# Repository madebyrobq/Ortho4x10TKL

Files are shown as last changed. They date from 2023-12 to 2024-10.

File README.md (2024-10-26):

# Ortho 4x10 TKL v0.1

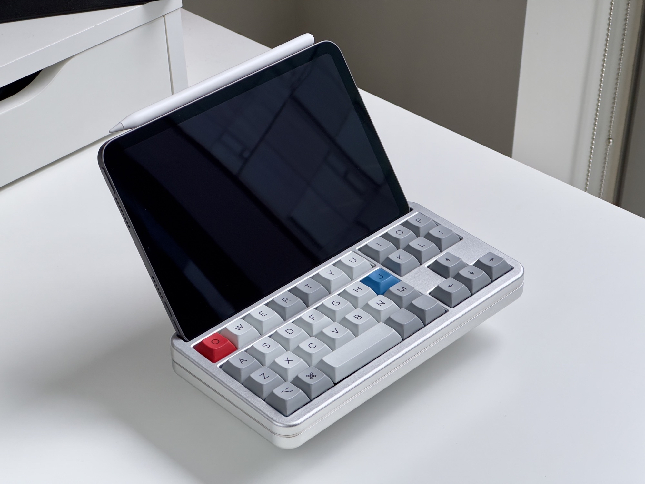
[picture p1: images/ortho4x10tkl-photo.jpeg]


### Summary

An open-source custom mechanical keyboard featuring
* 4x10 ortholinear 'tenkeyless' style layout
* Raspberry Pi RP2040 integrated microcontroller
* USB-C
* Hotswap sockets
* Fully factory-assembled PCBA
* QMK Vial firmware

### Goals

The goals of this project were:
1. Learn how to make a working PCBA mechanical keyboard
2. Keep hardware features to the minimum (no LEDs, OLED, encoders, etc.)
3. Fun and delighful > practical
4. Companion for iPad Mini (6th gen)

### Layout

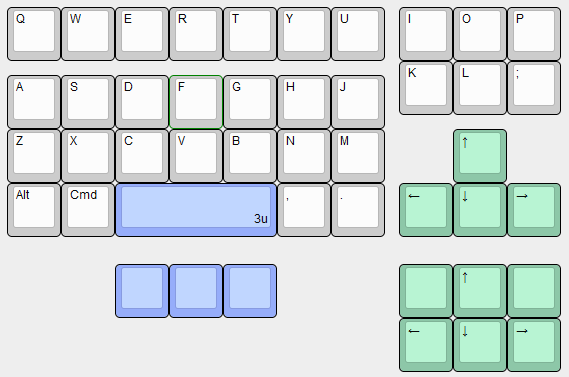
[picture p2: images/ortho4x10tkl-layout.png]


Spacebar cluster supports 3x1U and 1x3U layouts. Stabilizers are not currently supported but can be substituted with loose switches if desired.

Arrow cluster supports 4 or 6 keys, although the top cases in this repo will cover up 2 of them. Still, the switches are there if you prefer to have them.

### Keymap

This is my keymap, note that with VIAL firmware some setup will be manual in the VIAL application or loaded from a saved layout

```
Default Layer:
┌───────┬───────┬───────┬───────┬───────┬───────┬───────┐┌───────┬───────┬───────┐
│   Q (TAB) W   │   E   │   R   │   T   │   Y   │   U   ││   I   │   O (DEL) P   │
└───────┴───────┴───────┴───────┴───────┴───────┴───────┘├───────┼───────┼───────┤
┌───────┬───────┬───────┬───────┬───────┬───────┬───────┐│   K   │   L (ENT) ;   │
│   A (ESC) S   │   D   │   F   │   G   │   H   │   J   │└───────┴───────┴───────┘
├───────┼───────┼───────┼───────┼───────┼───────┼───────┤┌       ┌───────┐       ┐
│  Z(⇧) │   X   │   C   │   V   │   B   │   N   │  M(⇧) │  PG DN │   Up  │ PG UP
├───────┼───────┼───────┼───────┼───────┼───────┼───────┤┌───────┼───────┼───────┐
│   ⌥   │   ⌘   │         Space         │   ,   │   .   ││  Left │  Down │ Right │
└───────┴───────┴───────┴───────┴───────┴───────┴───────┘└───────┴───────┴───────┘

Raise Layer:
┌───────┬───────┬───────┬───────┬───────┬───────┬───────┐┌───────┬───────┬───────┐
│   1  (`)  2   │   3   │   4   │   -   │   +   │       ││   [   │   ]   |   '   │
└───────┴───────┴───────┴───────┴───────┴───────┴───────┘├───────┼───────┼───────┤
┌───────┬───────┬───────┬───────┬───────┬───────┬───────┐│   (   │   )   |       │
│   4   |   5   │   6   │   0   │   /   │   *   │   =   │└───────┴───────┴───────┘
├───────┼───────┼───────┼───────┼───────┼───────┼───────┤┌       ┌───────┐       ┐
│  7(⇧) │   8   │   9   │   .   │   |   │   &   │   ?   │        │   ⇧   │       
├───────┼───────┼───────┼───────┼───────┼───────┼───────┤┌───────┼───────┼───────┐
│   ⌥   │  0(⌘) │                       │       │       ││   <   │   ⌃   │   >   │
└───────┴───────┴───────┴───────┴───────┴───────┴───────┘└───────┴───────┴───────┘
```

Key Overrides I use:
* `Shift` + `,` = `!`
* `Shift` + `.` = `?`
* `Shift` + `/` = `\`
* `Cmd` + `Q` = `Cmd` + `Tab` (quit too many apps adapting to this layout lol)

### PCB

Version 0.1 - First PCBA ordered from JLCPCB, it works!

### Firmware

Vial firmware is compiled in [here](vial/), along with saved keymaps (including combos and settings that could not be baked into the firmware) which can be loaded from the Vial application.

QMK firmware source will be added soon

### Case & Parts

Can be 3D printed or CNC'd. The 3D printed variants simply have hex holes to fit a standoff, which can be glued in and act as the thread for the screws. The CNC files will work for 3D printing as well if the holes on the top case are tapped manually.

| Part | Note |
|---|:---:|
| PCBA | [PCB files](PCB/) |
| Plate | [Laser Cut Plate](Case/)<br/>1.5mm brass / steel / etc. |
| Top Case | [Multiple options](Case/) |
| Bottom Case | [STL or STEP](Case/) |
| Screws | 4x M2.5 10mm counter sunk |
| Hex standoffs or nuts<br>(if 3D printing) | 4x M2.5 5mm |
| Rubber feet/bumpons | 4x |
| Switches and keycaps | 36 to 40 each |

## What's Next

I'm quite satisfied with getting this working, and I had to order a minimum of 5 PCBs so I don't plan on making more for a while. But if you find this and use it as an example, here are some ideas of what could be added or improved:
* Layouts
  * Support for more spacebar layouts like 2u in between the existing keys
  * Clip-in stabilizer support
* PCB design
  * Move the USB - since the iPad plugs in on the right it could be nice and compact to put the USB on the right edge of the case
  * Cluster or consolidate the Reset and Boot pins. I was more concerned with finding a place they fit and were easy to route, but it's quite odd especially now that I know you have to either press them both simultaneously or hold Boot while plugging in the USB (which I put on opposite sides).
  * Improve routing and reduce PCB "forehead". But I kind of like the look.
  * Try another MCU. The Raspberry Pi is totally fine, but there are other MCUs that have more packaged features like flash and crystal, so that would be fewer parts to order, and easier to route.
* Other hardware features
  * Add more hardware features like LEDs, ESD, etc.
  * Breakout pins to add hardware features or a daughter board later
* Case
  * Support for more devices
  * Perfect the USB-C cutout
  * Design out of a single piece of aluminum to reduce cost

## Thanks to

For excellent custom keyboard and PCB tutorials (highly recommend starting here if you are interested): [Noah Kiser](https://www.youtube.com/@noahkiser), [Joe Scotto](https://www.youtube.com/@joe_scotto)

For layout inspiration: Zicodia ("LMAO"), tominabox1 and whydobearsxplod ("QAZ"), Jack Humbert ("Planck")

## Disclaimer

**Offered without warranty or liability! Use / modify / order at your own risk. No customer support.**

For a first attempt, and as a hobby project, it turned out quite well! But this was just for fun and not made with the rigor or intent to commercialize it (for now...) so it isn't perfect.

Feel free to use this repository under the license provided. If it helps you make something cool, I would be happy to see it!

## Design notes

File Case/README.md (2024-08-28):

# Case

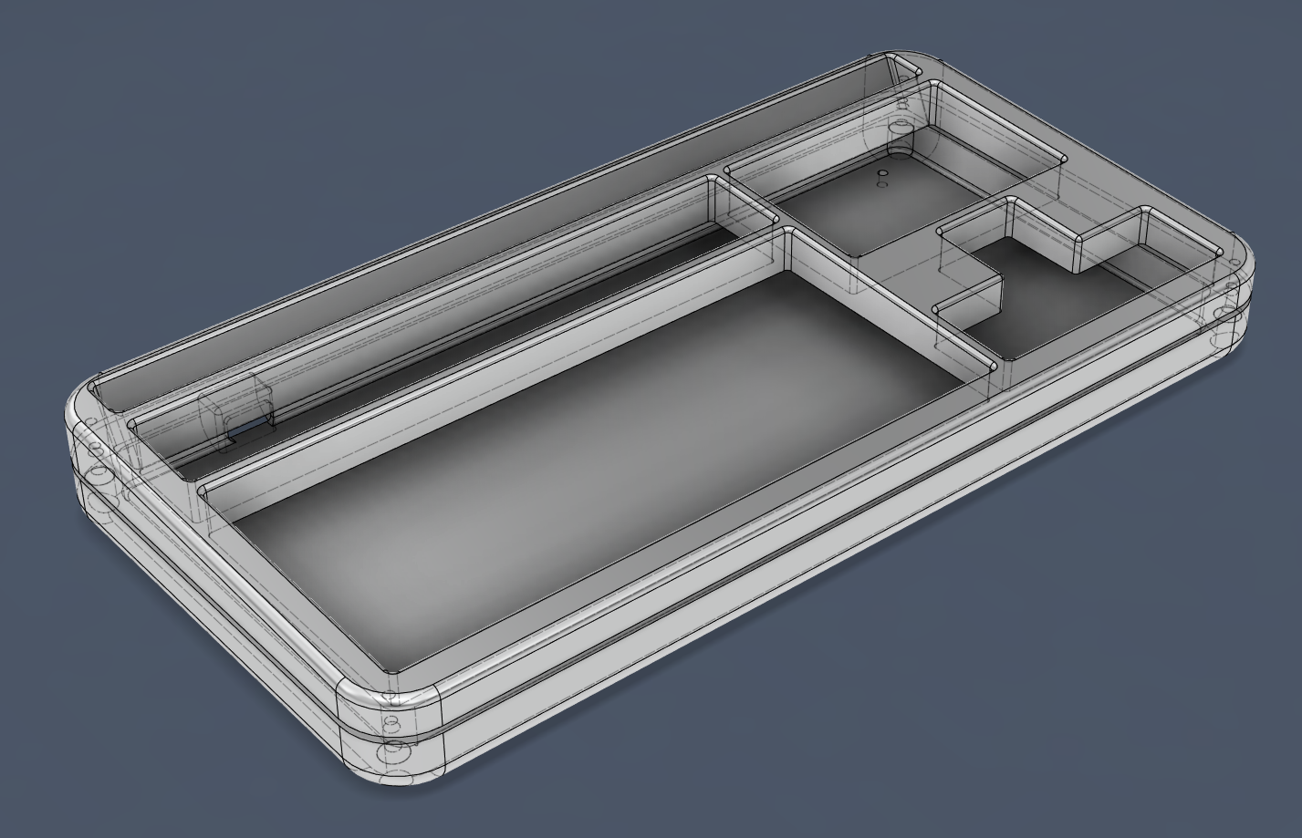
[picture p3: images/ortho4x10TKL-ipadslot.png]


## Plate

To start, get a plate laser cut in 1.5mm

The plate in this repository is _somewhat_ future-proofed with room for multiple spacebar layouts - however, the PCB itself doesn't support all of them as of v0.1

## Bottom Case

There is only one bottom case design at this time, just choose the format you need

## Top Case

Finally, the top case. There are several options:
1. iPad slot 
   1. Designed to hold an iPad mini 6th gen
   2. _May_ hold other devices up to 8mm thickness
   3. Slight 2° incline to add support (note: this does NOT tilt the keys themselves)
   4. Smaller 2mm bevels
2. Dimpled
   1. An aesthetic, gently sloped impression which can keep a pen from rolling away
3. Flat
   1. No embellishments

Top case must be chosen for the method of which it is made
* 3D Print (.stl) - requires hex standoffs
* CNC (.step) - requires threads as marked in the technical drawing
  * Can also be used to 3D print if threads are tapped manually

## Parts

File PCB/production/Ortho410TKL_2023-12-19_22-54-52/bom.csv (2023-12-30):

Designator | Footprint | Quantity | Value | LCSC Part #
C1, C12, C2, C4, C6 | 0402 | 5 | 1u
C10, C11 | 0402 | 2 | 22p
C13, C14, C15, C16, C5, C7, C8, C9 | 0402 | 8 | 100n
C3 | 0603 | 1 | 10u
D1, D10, D11, D12, D13, D14, D15, D16, D17, D18, D19, D2, D20, D21, D22, D23, D24, D25, D26, D27, D28, D29, D3, D30, D31, D32, D33, D34, D35, D36, D37, D38, D39, D4, D40, D5, D6, D7, D8, D9 | D_SOD-123 | 40 | D_Small
F1 | 1206 | 1 | Fuse_Small
J1 | USB_C_Receptacle_HRO_TYPE-C-31-M-12 | 1 | USB_C_Receptacle_USB2.0
J3 | PinHeader_1x05_P2.54mm_Vertical | 1 | Conn_01x05
MX1, MX10, MX11, MX12, MX13, MX14, MX15, MX16, MX17, MX18, MX19, MX2, MX20, MX21, MX22, MX23, MX24, MX25, MX26, MX27, MX28, MX29, MX3, MX30, MX31, MX32, MX33, MX34, MX35, MX36, MX37, MX38, MX39, MX4, MX40, MX5, MX6, MX7, MX8, MX9 | SW_MX_HS_1u | 40 | MX_SW_HS
R1, R2, R3, R8, R9 | 0402 | 5 | 5.1k
R4, R5 | 0402 | 2 | 27
R6, R7 | 0402 | 2 | 1k
SW_BOOT1, SW_RESET1 | SW_SPST_TL3342 | 2 | SW_Push
U1 | QFN-56-1EP_7x7mm_P0.4mm_EP3.2x3.2mm | 1 | RP2040
U2 | SOT-23-3 | 1 | XC6206PxxxMR
U4 | SOIC-8_5.23x5.23mm_P1.27mm | 1 | W25Q128JVS
Y1 | Crystal_SMD_3225-4Pin_3.2x2.5mm | 1 | Crystal_GND24

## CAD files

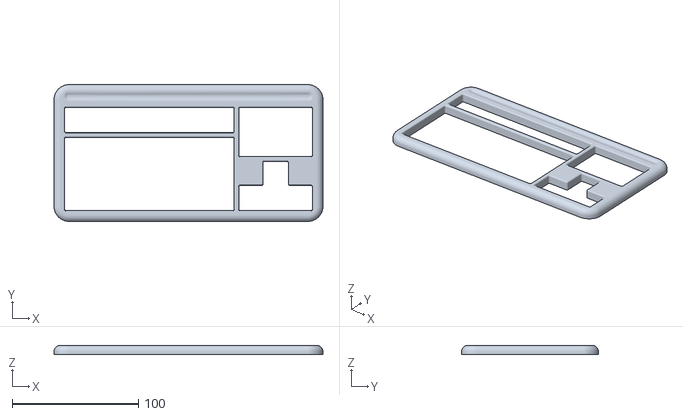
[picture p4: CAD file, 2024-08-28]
Case/3D Print/ortho4x10TKL-top-dimpled-3DP.stl
213.3 x 108.5 x 7.50

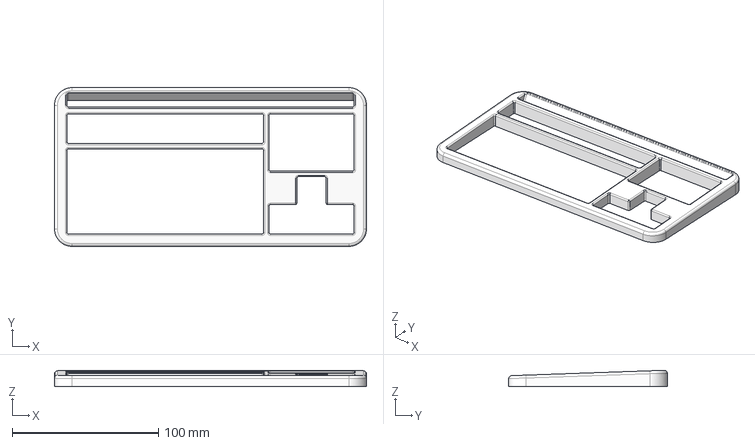
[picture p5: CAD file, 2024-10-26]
Case/CNC/ortho4x10tkl-top-ipadslot-cnc.step
213.3 x 108.5 x 11.2 mm

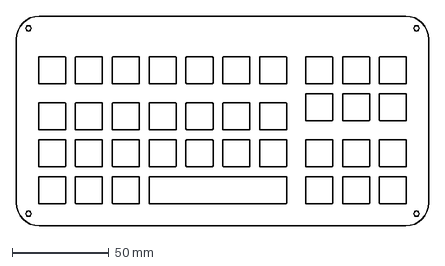
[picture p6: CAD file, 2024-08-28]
Case/Plate/ortho4x10TKL-plate.dxf
213.3 x 108.5 mm

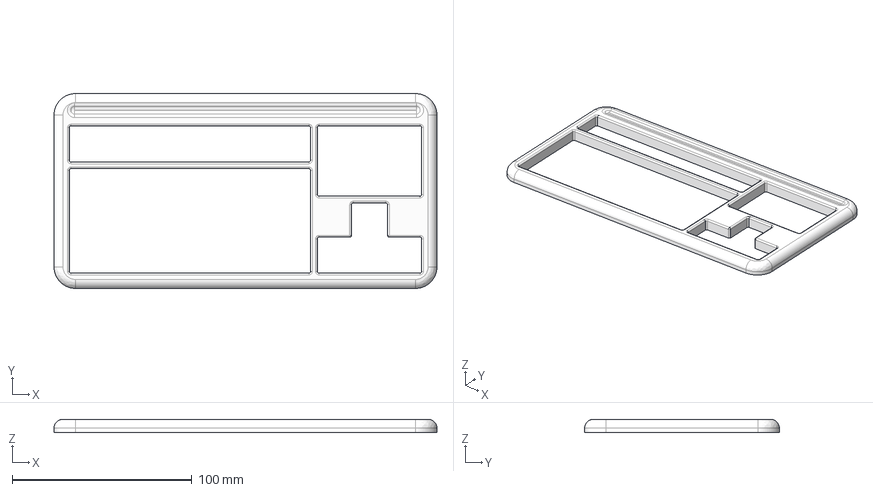
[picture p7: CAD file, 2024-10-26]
Case/CNC/ortho4x10tkl-top-dimpled-cnc.step
213.3 x 108.5 x 7.50 mm

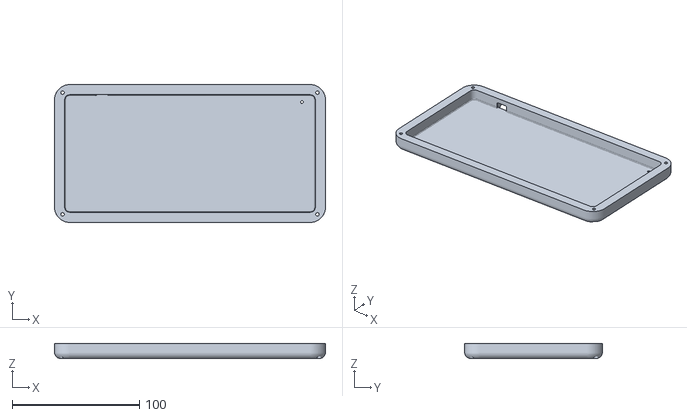
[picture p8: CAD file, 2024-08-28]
Case/3D Print/ortho4x10TKL-bottom-3DP.stl
213.3 x 108.5 x 12.0

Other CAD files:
Case/3D Print/ortho4x10TKL-top-flat-3DP.stl
Case/CNC/ortho4x10tkl-bottom-cnc.step
Case/3D Print/ortho4x10TKL-top-ipadslot-3DP.stl

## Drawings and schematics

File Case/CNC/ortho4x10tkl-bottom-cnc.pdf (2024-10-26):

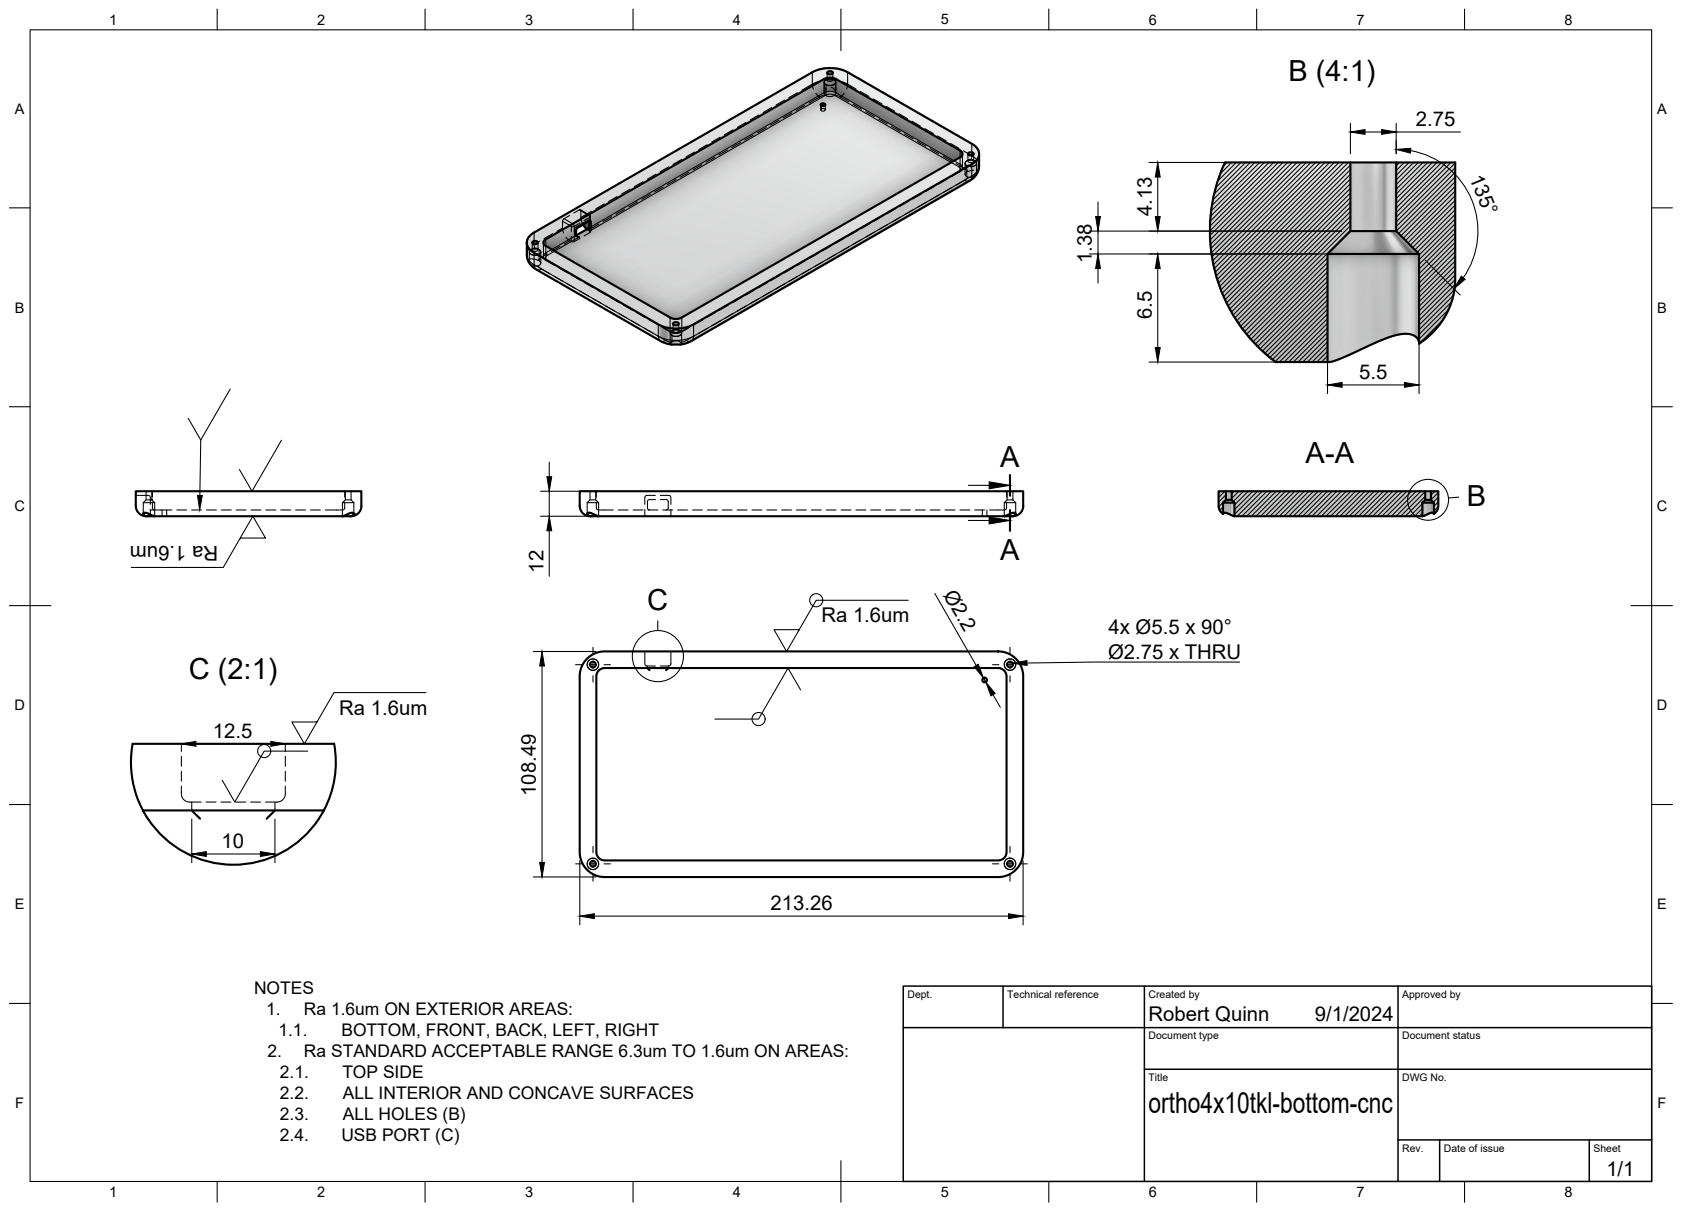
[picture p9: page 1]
Title; DWG No.; Rev.; Date of issue; Sheet; 4x Ø5.5 x 90° Ø2.75 x THRU

NOTES
1. Ra 1.6um ON EXTERIOR AREAS:
1.1. BOTTOM, FRONT, BACK, LEFT, RIGHT
2. Ra STANDARD ACCEPTABLE RANGE 6.3um TO 1.6um ON AREAS:
2.1. TOP SIDE
2.2. ALL INTERIOR AND CONCAVE SURFACES
2.3. ALL HOLES (B)
2.4. USB PORT (C)

Dept. | Technical reference | Created by Robert Quinn 9/1/2024 | Approved by

Document type | Document status

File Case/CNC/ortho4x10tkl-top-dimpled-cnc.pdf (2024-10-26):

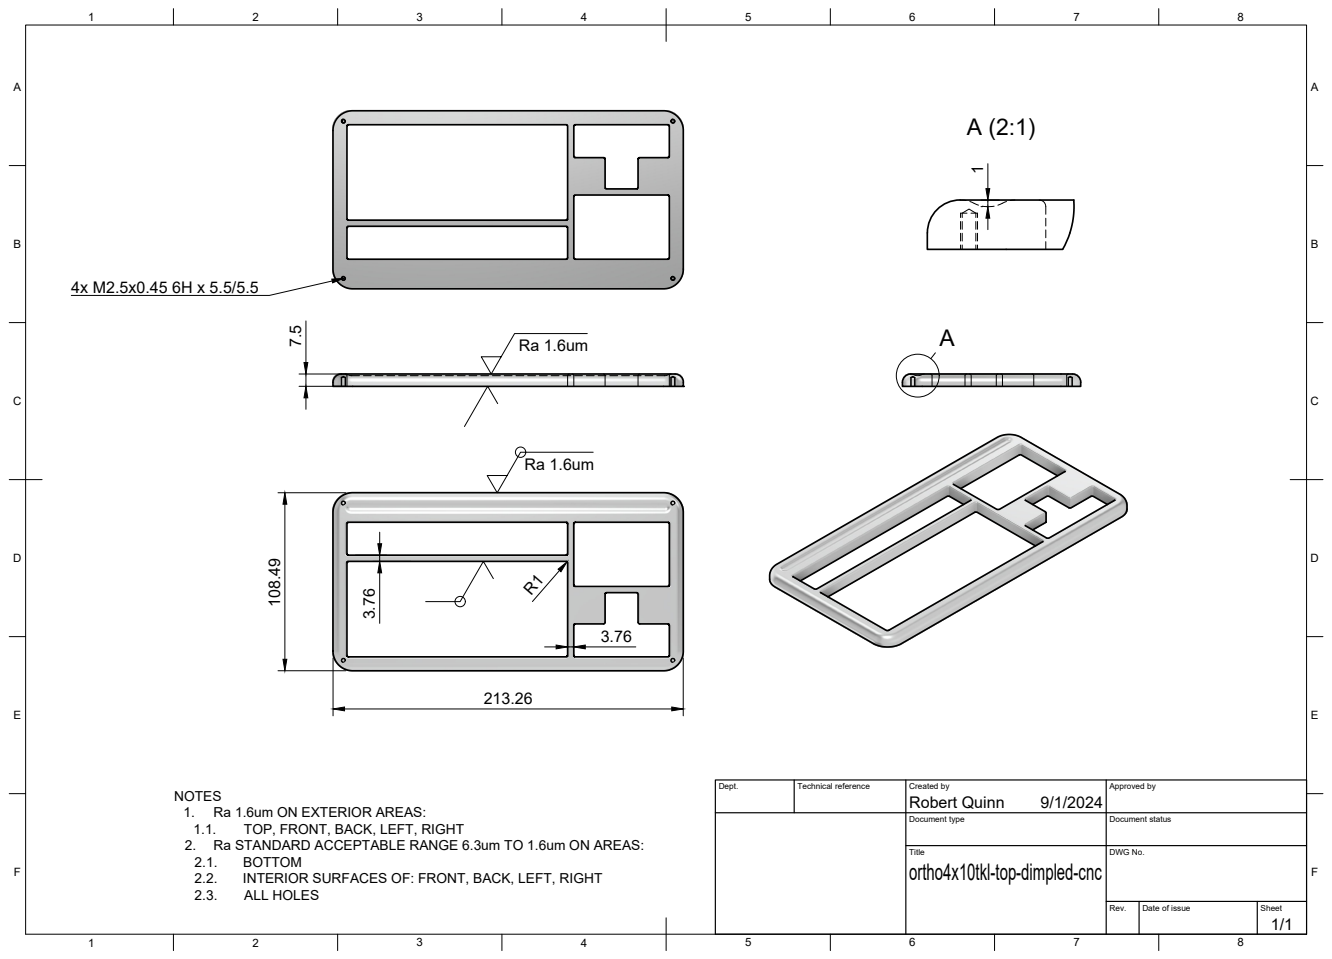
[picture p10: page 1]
Title; DWG No.; Rev.; Date of issue; Sheet

Dept. | Technical reference | Created by Robert Quinn 9/1/2024 | Approved by

NOTES
1. Ra 1.6um ON EXTERIOR AREAS:
1.1. TOP, FRONT, BACK, LEFT, RIGHT
2. Ra STANDARD ACCEPTABLE RANGE 6.3um TO 1.6um ON AREAS:
2.1. BOTTOM
2.2. INTERIOR SURFACES OF: FRONT, BACK, LEFT, RIGHT
2.3. ALL HOLES

Document type | Document status

ortho4x10tkl-top-dimpled-cnc

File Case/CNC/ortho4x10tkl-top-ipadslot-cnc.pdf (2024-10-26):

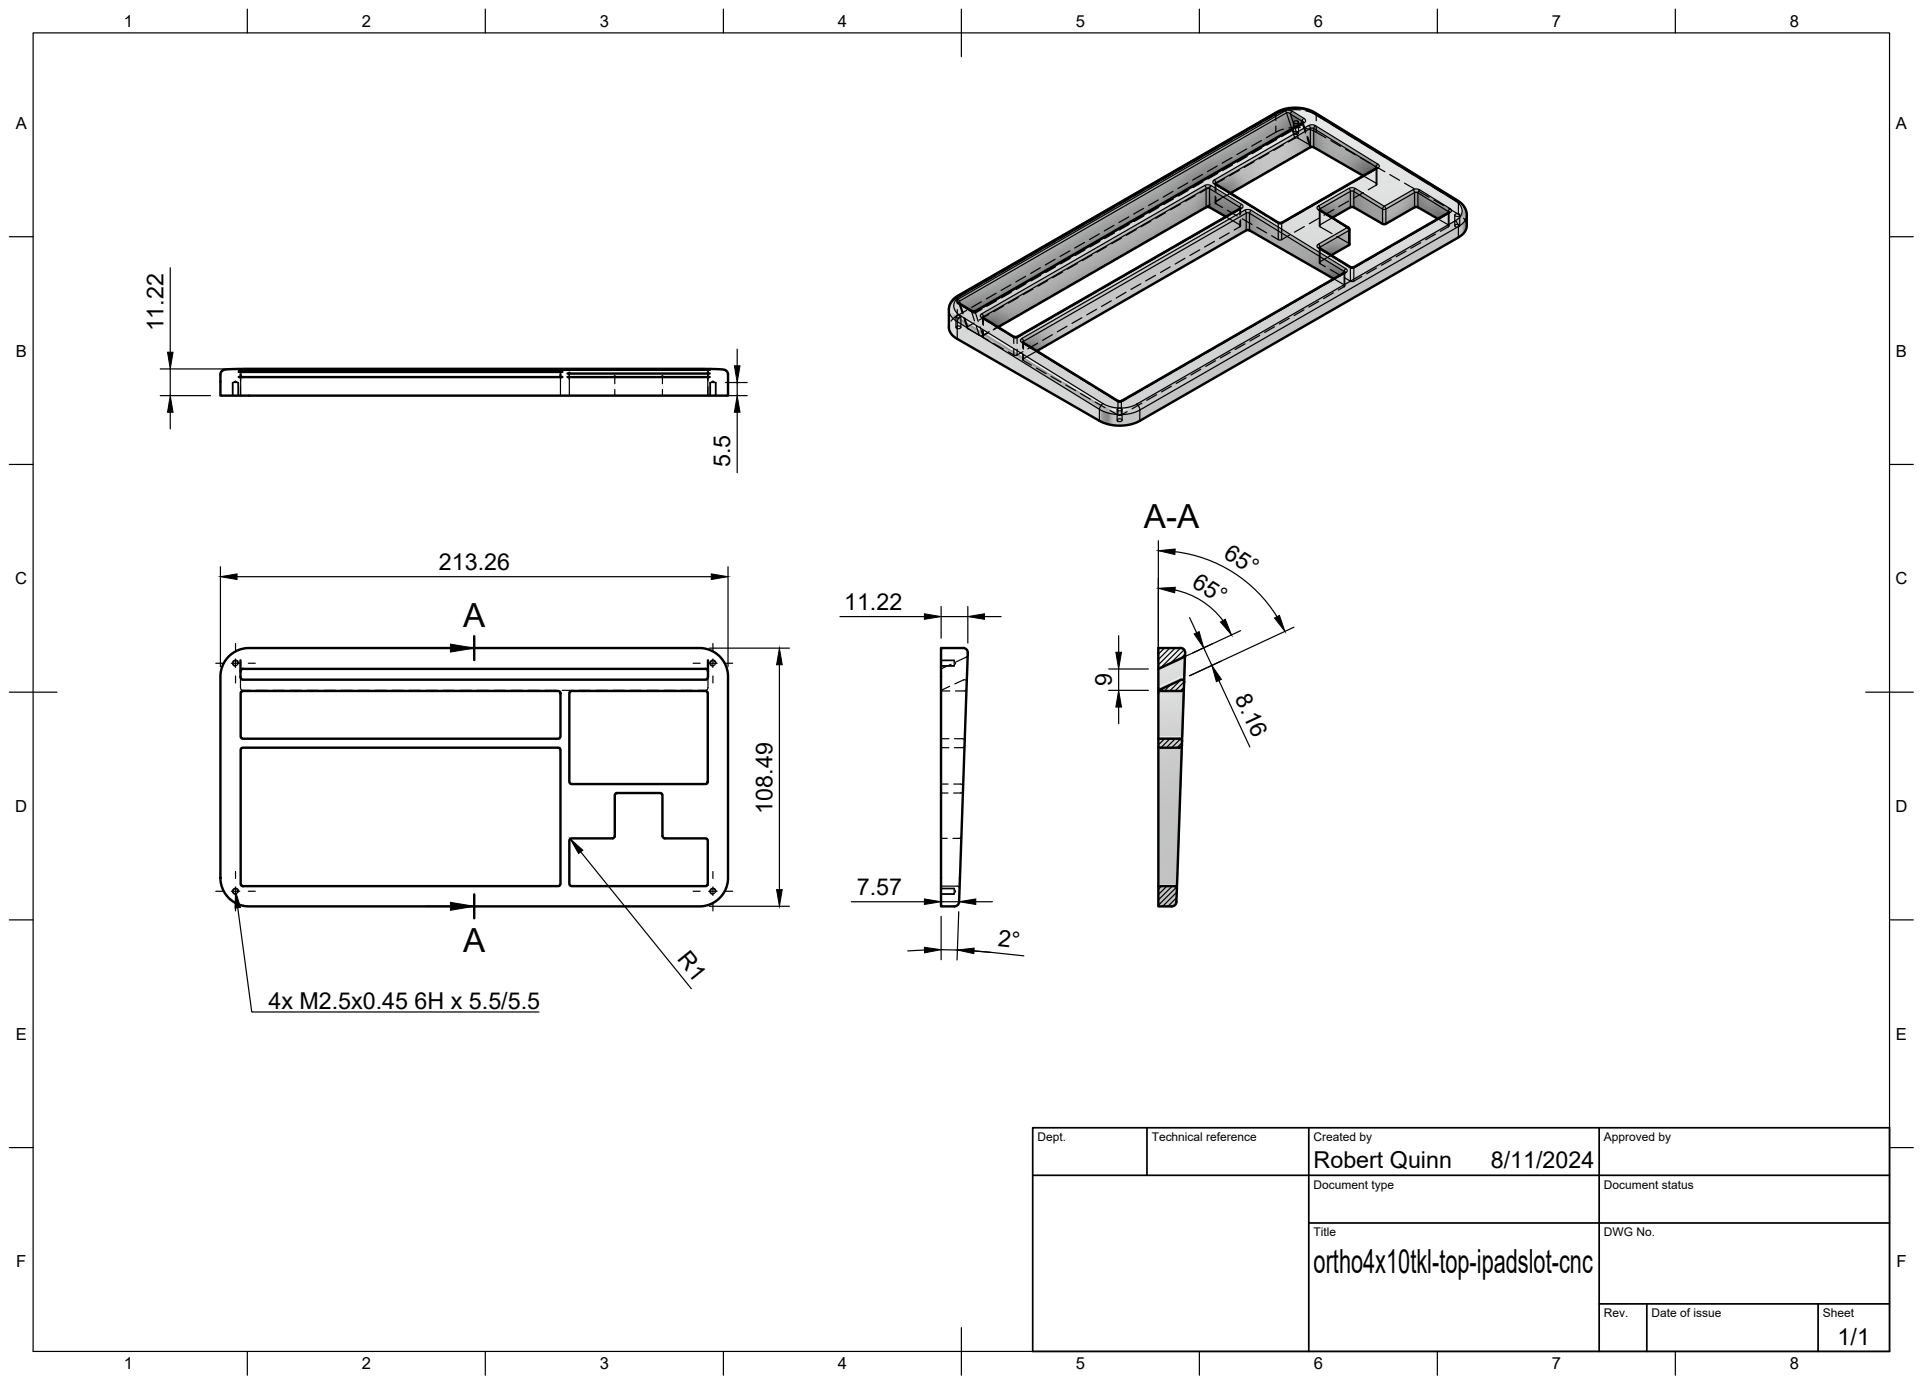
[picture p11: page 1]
Title; DWG No.; Rev.; Date of issue; Sheet

Dept. | Technical reference | Created by Robert Quinn 8/11/2024 | Approved by

Document type | Document status

ortho4x10tkl-top-ipadslot-cnc

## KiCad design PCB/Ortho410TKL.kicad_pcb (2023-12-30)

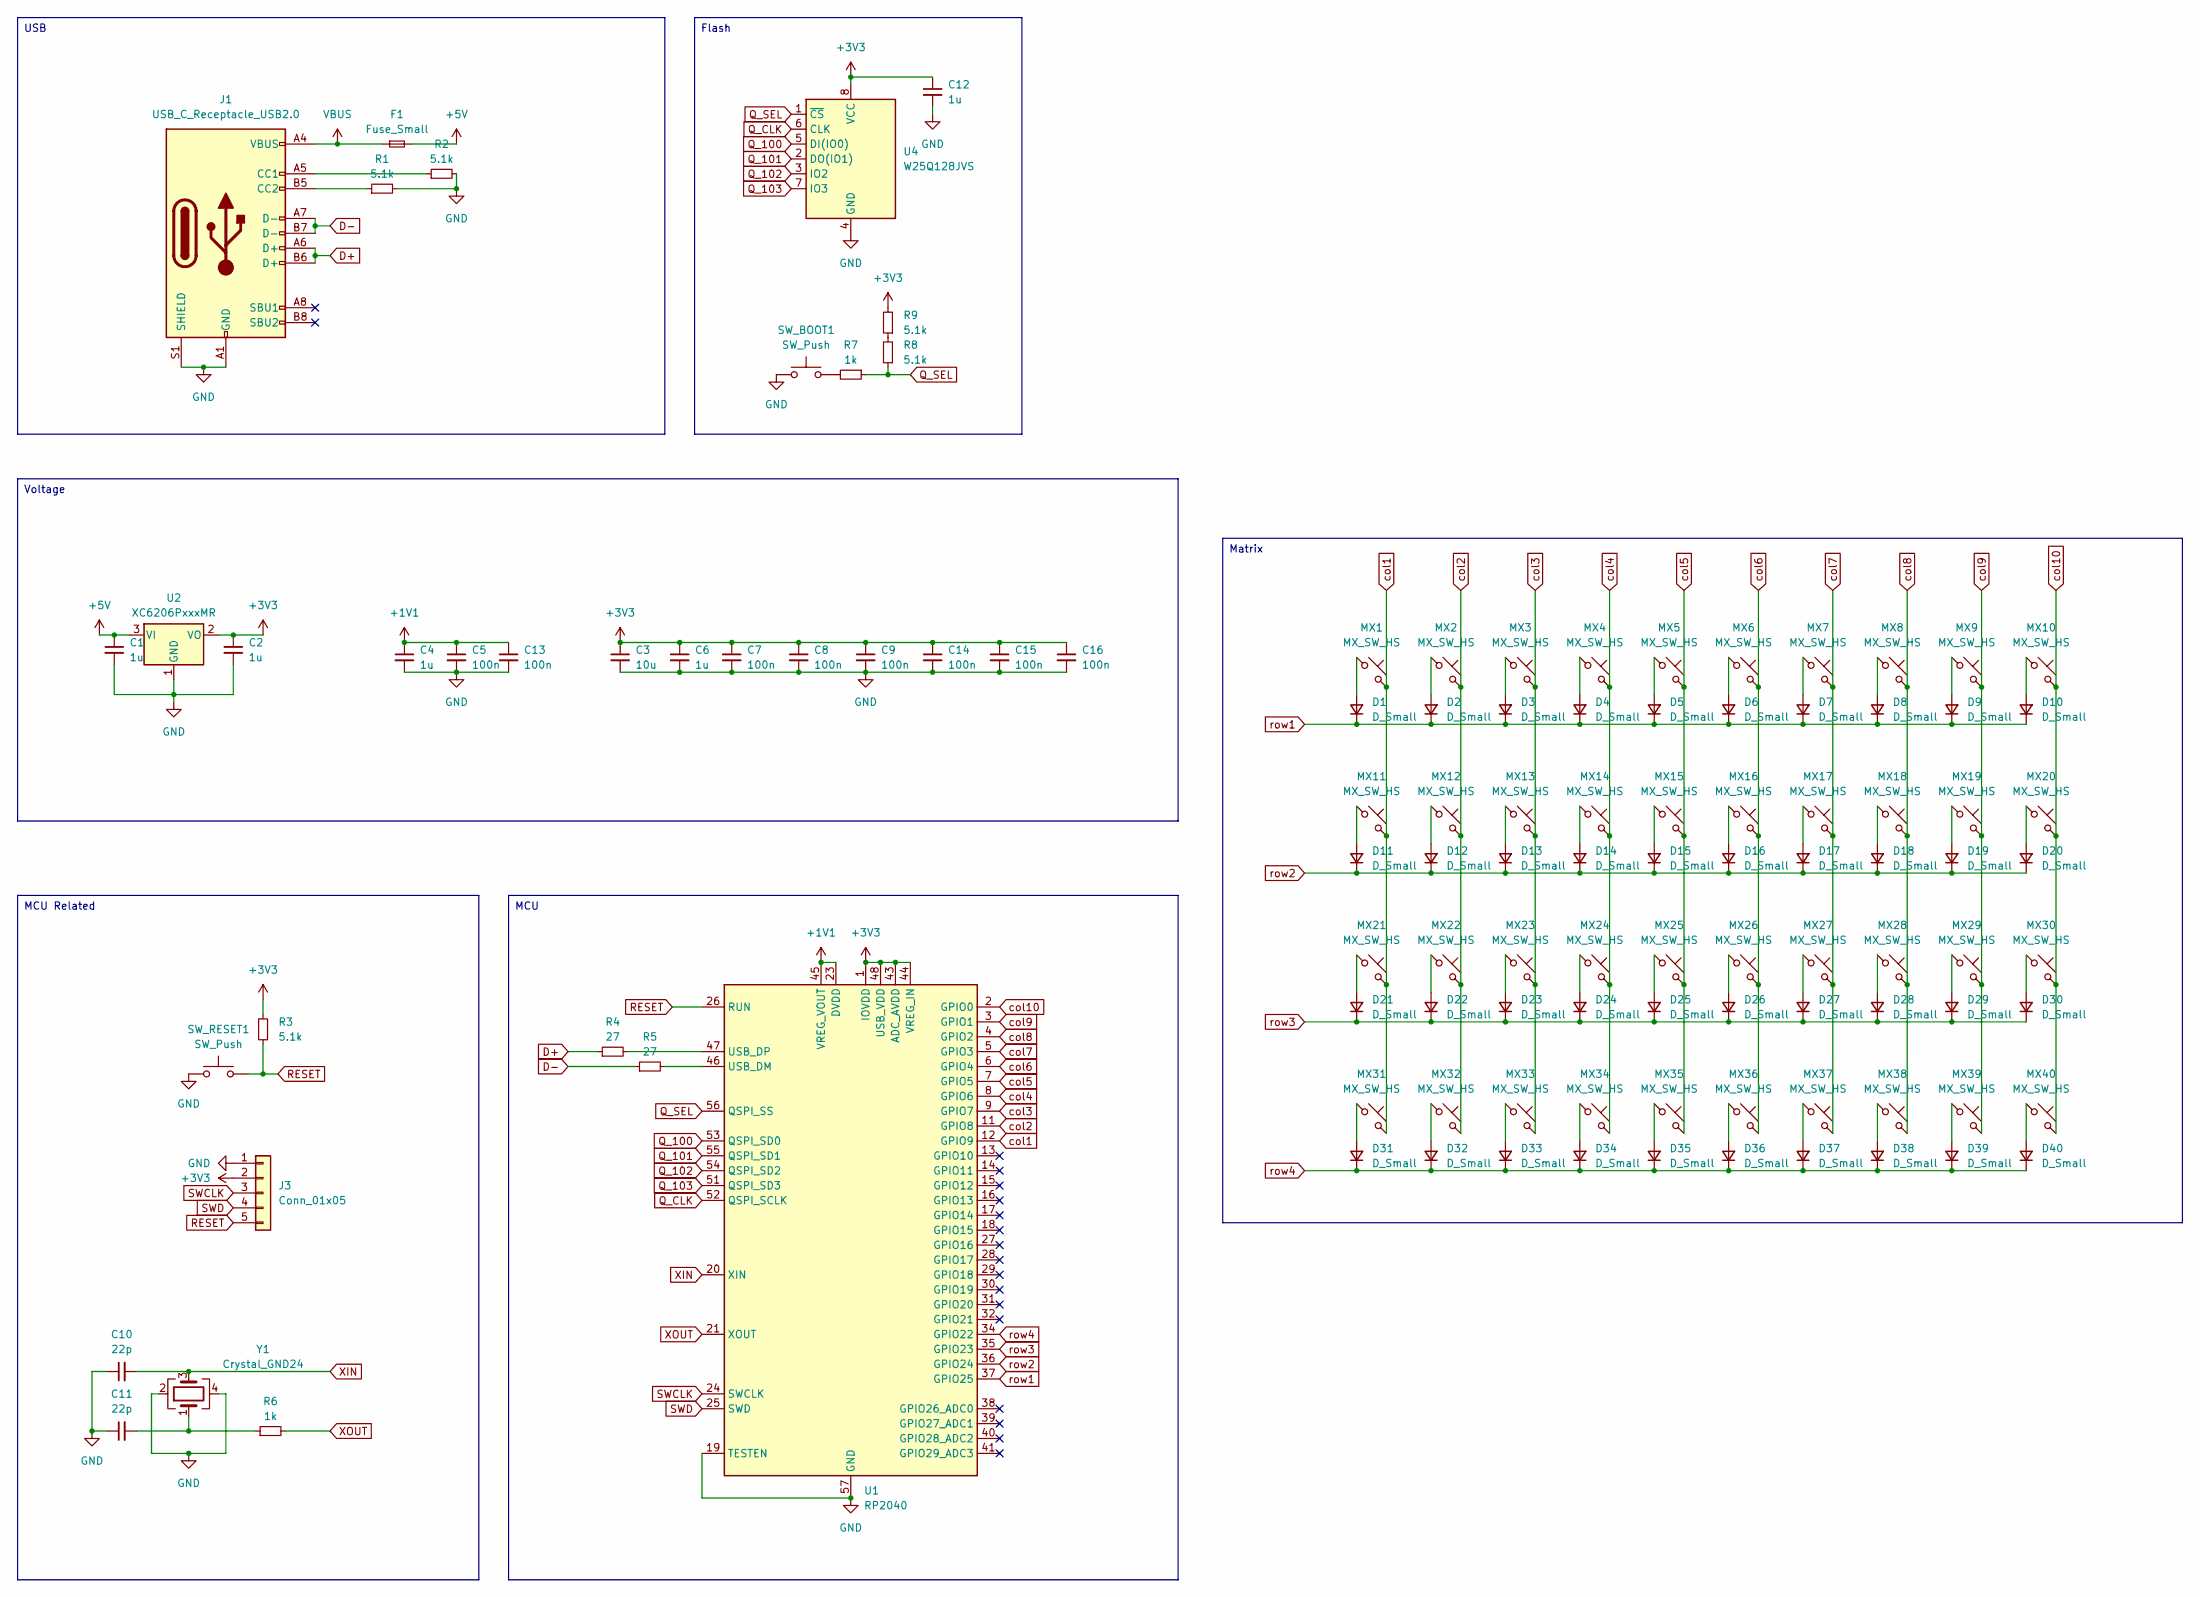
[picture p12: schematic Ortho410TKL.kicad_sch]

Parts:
C1, C2, C4, C6, C12: 1u; C_0402_1005Metric
C3: 10u; C_0603_1608Metric
C5, C7, C8, C9, C13, C14, C15, C16: 100n; C_0402_1005Metric
C10, C11: 22p; C_0402_1005Metric
D1, D2, D3, D4, D5, D6, D7, D8, D9, D10, D11, D12, D13, D14, D15, D16, D17, D18, D19, D20, D21, D22, D23, D24, D25, D26, D27, D28, D29, D30, D31, D32, D33, D34, D35, D36, D37, D38, D39, D40: D_Small; D_SOD-123
F1: Fuse_Small; Fuse_1206_3216Metric
J1: USB_C_Receptacle_USB2.0; USB_C_Receptacle_HRO_TYPE-C-31-M-12
J3: Conn_01x05; PinHeader_1x05_P2.54mm_Vertical
MX1, MX2, MX3, MX4, MX5, MX6, MX7, MX8, MX9, MX10, MX11, MX12, MX13, MX14, MX15, MX16, MX17, MX18, MX19, MX20, MX21, MX22, MX23, MX24, MX25, MX26, MX27, MX28, MX29, MX30, MX31, MX32, MX33, MX34, MX35, MX36, MX37, MX38, MX39, MX40: MX_SW_HS; SW_MX_HS_1u
R1, R2, R3, R8, R9: 5.1k; R_0402_1005Metric
R4, R5: 27; R_0402_1005Metric
R6, R7: 1k; R_0402_1005Metric
SW_BOOT1: SW_Push; SW_SPST_TL3342
SW_RESET1: SW_Push; SW_SPST_TL3342
U1: RP2040; QFN-56-1EP_7x7mm_P0.4mm_EP3.2x3.2mm
U2: XC6206PxxxMR; SOT-23-3
U4: W25Q128JVS; SOIC-8_5.23x5.23mm_P1.27mm
Y1: Crystal_GND24; Crystal_SMD_3225-4Pin_3.2x2.5mm

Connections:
+1V1: C4.1, C5.1, C13.1, U1.23 (DVDD), U1.45 (VREG_VOUT), U1.50 (DVDD)
+3V3: C2.1, C3.1, C6.1, C7.1, C8.1, C9.1, C12.1, C14.1, C15.1, C16.1, J3.2, R3.2, R9.2, U1.1 (IOVDD), U1.10 (IOVDD), U1.22 (IOVDD), U1.33 (IOVDD), U1.42 (IOVDD), U1.43 (ADC_AVDD), U1.44 (VREG_IN), U1.48 (USB_VDD), U1.49 (IOVDD), U2.2 (VO), U4.8 (VCC)
+5V: C1.1, F1.2, U2.3 (VI)
D+: J1.A6 (D+), J1.B6 (D+), R4.1
D-: J1.A7 (D-), J1.B7 (D-), R5.1
GND: C1.2, C2.2, C3.2, C4.2, C5.2, C6.2, C7.2, C8.2, C9.2, C10.1, C11.1, C12.2, C13.2, C14.2, C15.2, C16.2, J1.A1 (GND), J1.A12 (GND), J1.B1 (GND), J1.B12 (GND), J1.S1 (SHIELD), J3.1, R1.2, R2.2, SW_BOOT1.1, SW_RESET1.1, U1.19 (TESTEN), U1.57 (GND), U2.1 (GND), U4.4 (GND), Y1.2, Y1.4
unnamed: C11.2, R6.1, Y1.1
unnamed: D1.2 (A), MX1.1
unnamed: D2.2 (A), MX2.1
unnamed: D3.2 (A), MX3.1
unnamed: D4.2 (A), MX4.1
unnamed: D5.2 (A), MX5.1
unnamed: D6.2 (A), MX6.1
unnamed: D7.2 (A), MX7.1
unnamed: D8.2 (A), MX8.1
unnamed: D9.2 (A), MX9.1
unnamed: D10.2 (A), MX10.1
unnamed: D11.2 (A), MX11.1
unnamed: D12.2 (A), MX12.1
unnamed: D13.2 (A), MX13.1
unnamed: D14.2 (A), MX14.1
unnamed: D15.2 (A), MX15.1
unnamed: D16.2 (A), MX16.1
unnamed: D17.2 (A), MX17.1
unnamed: D18.2 (A), MX18.1
unnamed: D19.2 (A), MX19.1
unnamed: D20.2 (A), MX20.1
unnamed: D21.2 (A), MX21.1
unnamed: D22.2 (A), MX22.1
unnamed: D23.2 (A), MX23.1
unnamed: D24.2 (A), MX24.1
unnamed: D25.2 (A), MX25.1
unnamed: D26.2 (A), MX26.1
unnamed: D27.2 (A), MX27.1
unnamed: D28.2 (A), MX28.1
unnamed: D29.2 (A), MX29.1
unnamed: D30.2 (A), MX30.1
unnamed: D31.2 (A), MX31.1
unnamed: D32.2 (A), MX32.1
unnamed: D33.2 (A), MX33.1
unnamed: D34.2 (A), MX34.1
unnamed: D35.2 (A), MX35.1
unnamed: D36.2 (A), MX36.1
unnamed: D37.2 (A), MX37.1
unnamed: D38.2 (A), MX38.1
unnamed: D39.2 (A), MX39.1
unnamed: D40.2 (A), MX40.1
unnamed: J1.A5 (CC1), R2.1
unnamed: J1.B5 (CC2), R1.1
unnamed: R7.2, SW_BOOT1.2
unnamed: R8.2, R9.1
unnamed: R5.2, U1.46 (USB_DM)
unnamed: R4.2, U1.47 (USB_DP)
Q_100: U1.53 (QSPI_SD0), U4.5 (DI(IO0))
Q_101: U1.55 (QSPI_SD1), U4.2 (DO(IO1))
Q_102: U1.54 (QSPI_SD2), U4.3 (IO2)
Q_103: U1.51 (QSPI_SD3), U4.7 (IO3)
Q_CLK: U1.52 (QSPI_SCLK), U4.6 (CLK)
Q_SEL: R7.1, R8.1, U1.56 (QSPI_SS), U4.1 (~CS)
RESET: J3.5, R3.1, SW_RESET1.2, U1.26 (RUN)
SWCLK: J3.3, U1.24 (SWCLK)
SWD: J3.4, U1.25 (SWD)
VBUS: F1.1, J1.A4 (VBUS), J1.A9 (VBUS), J1.B4 (VBUS), J1.B9 (VBUS)
XIN: C10.2, U1.20 (XIN), Y1.3
XOUT: R6.2, U1.21 (XOUT)
col1: MX1.2, MX11.2, MX21.2, MX31.2, U1.12 (GPIO9)
col2: MX2.2, MX12.2, MX22.2, MX32.2, U1.11 (GPIO8)
col3: MX3.2, MX13.2, MX23.2, MX33.2, U1.9 (GPIO7)
col4: MX4.2, MX14.2, MX24.2, MX34.2, U1.8 (GPIO6)
col5: MX5.2, MX15.2, MX25.2, MX35.2, U1.7 (GPIO5)
col6: MX6.2, MX16.2, MX26.2, MX36.2, U1.6 (GPIO4)
col7: MX7.2, MX17.2, MX27.2, MX37.2, U1.5 (GPIO3)
col8: MX8.2, MX18.2, MX28.2, MX38.2, U1.4 (GPIO2)
col9: MX9.2, MX19.2, MX29.2, MX39.2, U1.3 (GPIO1)
col10: MX10.2, MX20.2, MX30.2, MX40.2, U1.2 (GPIO0)
row1: D1.1 (K), D2.1 (K), D3.1 (K), D4.1 (K), D5.1 (K), D6.1 (K), D7.1 (K), D8.1 (K), D9.1 (K), D10.1 (K), U1.37 (GPIO25)
row2: D11.1 (K), D12.1 (K), D13.1 (K), D14.1 (K), D15.1 (K), D16.1 (K), D17.1 (K), D18.1 (K), D19.1 (K), D20.1 (K), U1.36 (GPIO24)
row3: D21.1 (K), D22.1 (K), D23.1 (K), D24.1 (K), D25.1 (K), D26.1 (K), D27.1 (K), D28.1 (K), D29.1 (K), D30.1 (K), U1.35 (GPIO23)
row4: D31.1 (K), D32.1 (K), D33.1 (K), D34.1 (K), D35.1 (K), D36.1 (K), D37.1 (K), D38.1 (K), D39.1 (K), D40.1 (K), U1.34 (GPIO22)

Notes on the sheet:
Flash
MCU
Matrix
Voltage
MCU Related
USB

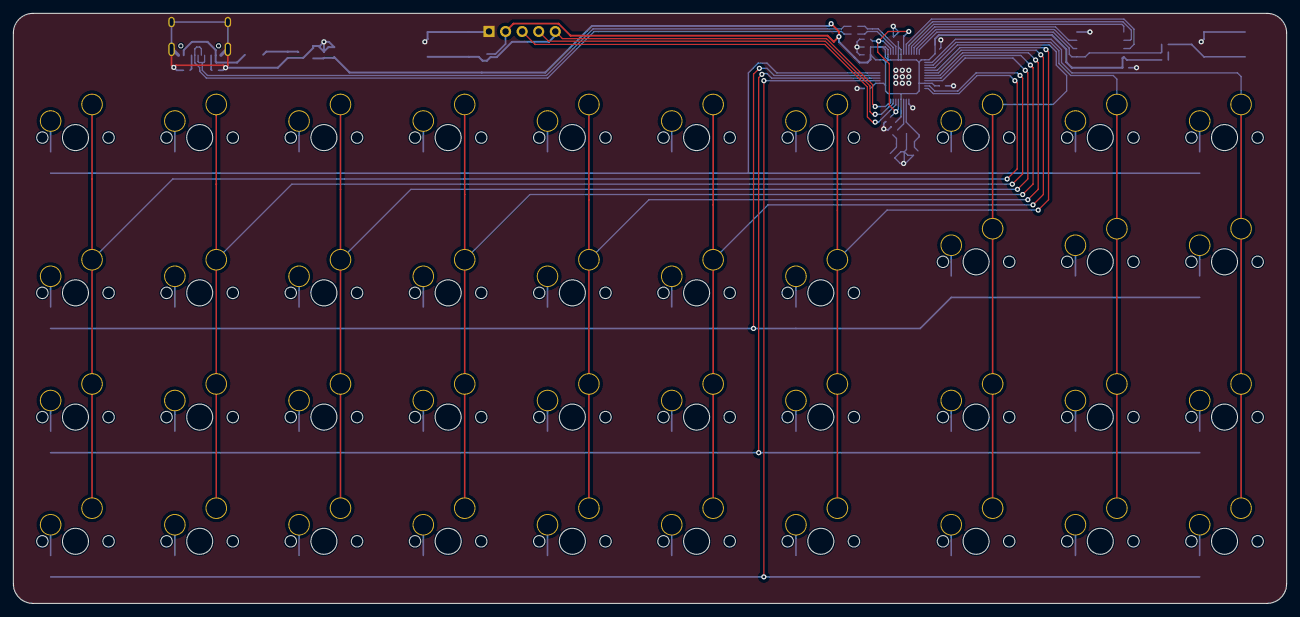
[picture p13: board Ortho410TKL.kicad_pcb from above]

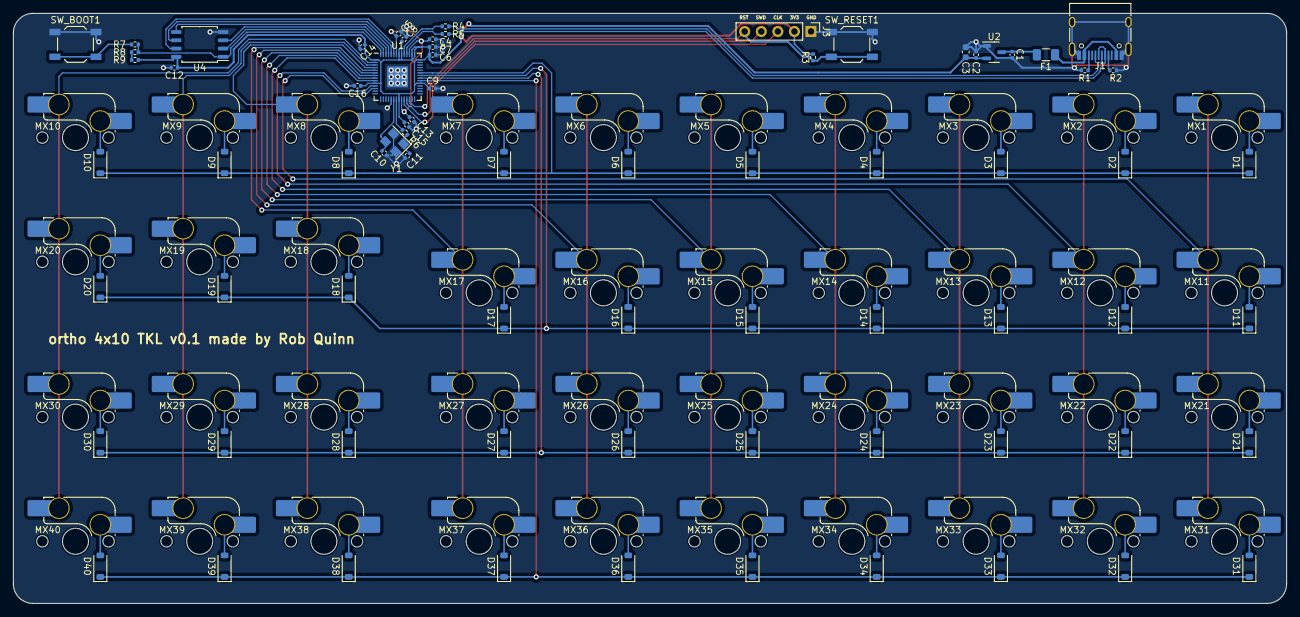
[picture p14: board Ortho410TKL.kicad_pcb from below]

Board: 2 copper layers, 195.3 x 90.5 mm, 114 parts (114 on the bottom side), 79 nets.

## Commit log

2023-12-30 initial commit of pcb files
    [Ortho410TKL.kicad_pcb, Ortho410TKL.kicad_sch, bom.csv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]
2024-08-28 start of case files
    [ortho4x10TKL-bottom-3DP.stl, ortho4x10TKL-plate.dxf, ortho4x10TKL-top-dimpled-3DP.stl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]
2024-10-26 cnc, photo
    [ortho4x10tkl-bottom-cnc.step, ortho4x10tkl-top-dimpled-cnc.step, ortho4x10tkl-top-ipadslot-cnc.step]
